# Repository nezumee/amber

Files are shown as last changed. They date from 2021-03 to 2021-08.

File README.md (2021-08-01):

# Amber
Personalized split keyboard based on [Zebra](https://github.com/nezumee/zebra) experimentation.

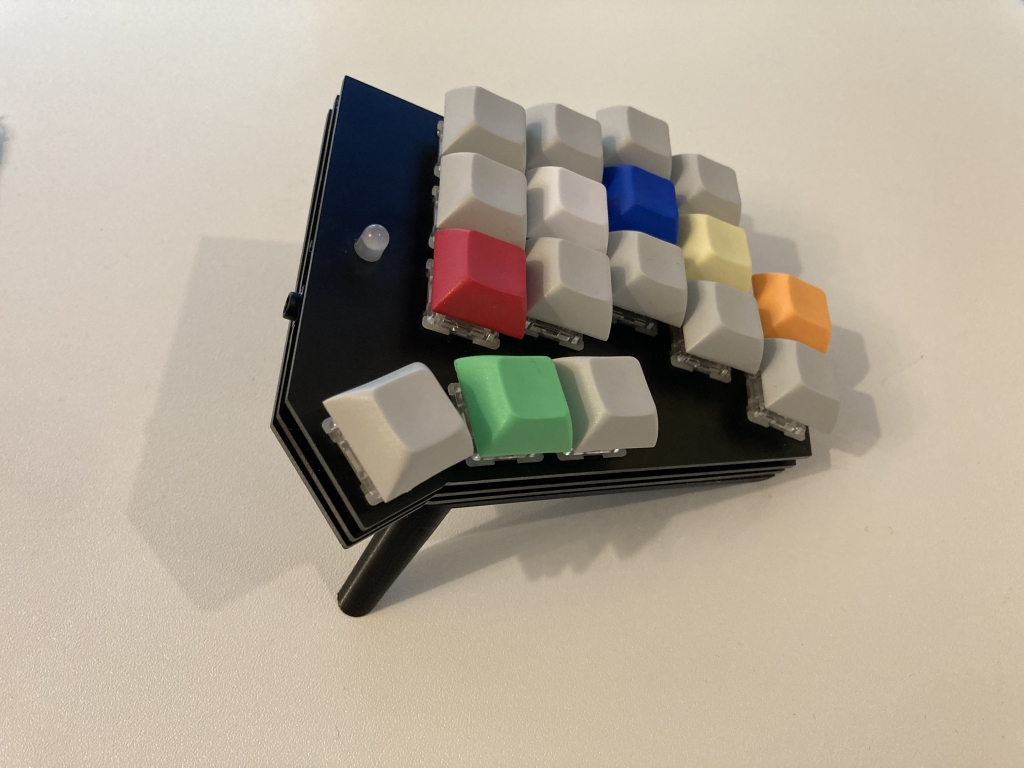
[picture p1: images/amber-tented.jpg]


# Bill of material

* PCB x2, switch plate PCB x2, bottom plate PCB x2 (see [gerber](gerber), all PCBs are reversible)
* ProMicro or equivalent x2 (if using something other than ProMicro, check if it will fit in the PCB cutout!)
* Peel-A-Way sockets x48 pins (https://keeb.io/products/peel-a-way-sockets-for-pro-micros)
* Mid-mount TRRS jack x2 (https://www.digikey.com/en/products/detail/cui-devices/SJ-43504-SMT-TR/2625173 or PJ342C in https://www.aliexpress.com/item/1005001299482943.html)
* Tactile switch x2 (https://www.digikey.com/en/products/detail/panasonic-electronic-components/EVQ-P7C01P/4429458)
* RGB LED x2 (https://www.digikey.com/en/products/detail/inolux/HV-5RGB60/7604616 or compatible)
* 1k Ohm resistor in 1206 size x2 (or other value, depending on how bright you want the indicator LED to be)
* EC11 rotary encoders x0-2
* N4148 x32 in DO-35 (through hole) or SOD123 (surface mount) form factor
* KailH sockets x32-34 (you need less than 34 if using encoders)
* Cherry MX compatible switches x32-34
* Keycaps
* TRRS cable

# Making a PCB sandwich keyboard starting with an ergogen definition
This design was created with help of the https://github.com/mrzealot/ergogen tool that makes it easier to generate keyboard plates and PCBs.

Rough steps used:
1. Generate PCB and outlines using ergogen: [ergogen.yaml](ergogen.yaml)
2. Create a Kicad schematic with switches and diodes, matching the ids created by ergogen, make a PCB based on that
3. Overwrite the Kicad PCB with the one coming from ergogen
4. Update PCB from schematic, preserving references but updating the nets and footprints as needed
5. Import the edges layer from ergogen outline, keep default position so outline matches the switch positions
6. Continue designing the PCB in Kicad as normal

# Fitting the ProMicro between the switch plate and PCB
Many keyboards using ProMicro (like Corne) either have the ProMicro exposed, or use a small plate to cover it separately from the switch plate. While the tech prototype look of showing the MCU is nice, sometimes you want something cleaner looking, and also less prone to gathering visible dust. With this in mind, I decided to make the front plate that serves both as a plate for the switches and also covers all the components on the PCB. This led to a few challenges:

1. Fit the ProMicro and its socket (yes, I didn't want to solder it to the PCB directly) between the PCB and the front plate. This required a surprising amount of effort:
  * Use the thinnest sockets I could find - Peel-a-way sockets (https://keeb.io/products/peel-a-way-sockets-for-pro-micros). They seem to be difficult to source, luckily I got some beforehand. Note that these sockets require bigger holes than you would normally have. My first iteration of the PCB had too narrow holes so they could not fit. 1.1mm in the second version is enough:
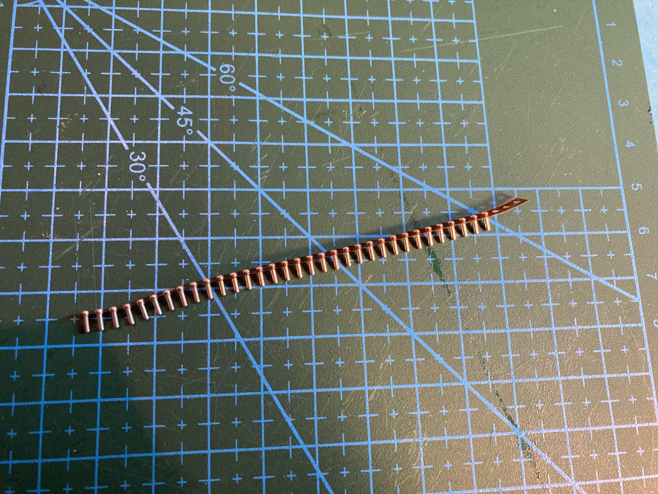
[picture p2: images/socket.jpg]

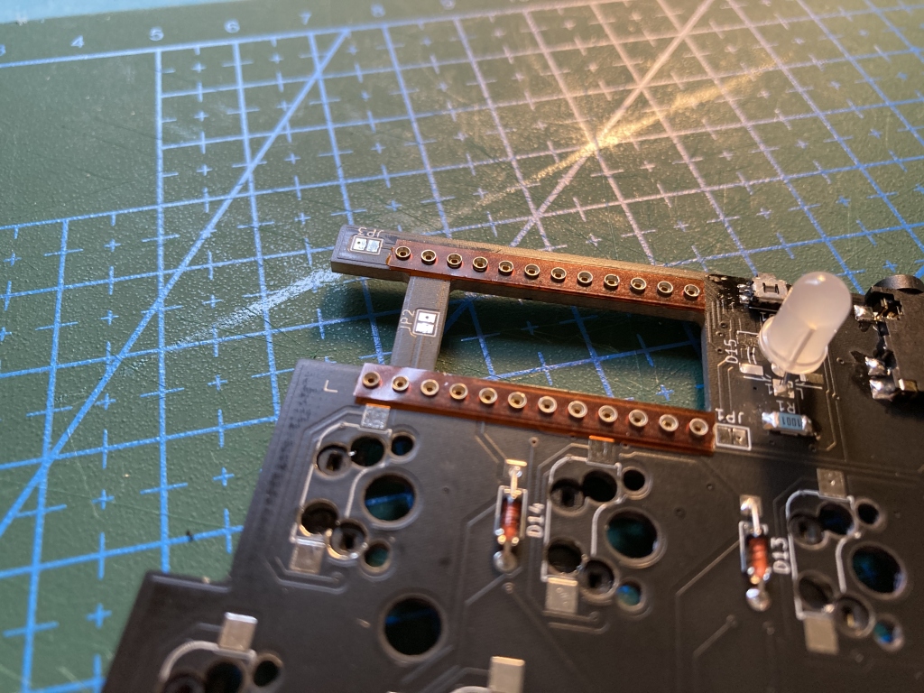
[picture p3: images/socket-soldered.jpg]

  * Mount ProMicro upside down
  * Make a cutout in the PCB to fit the components on ProMicro
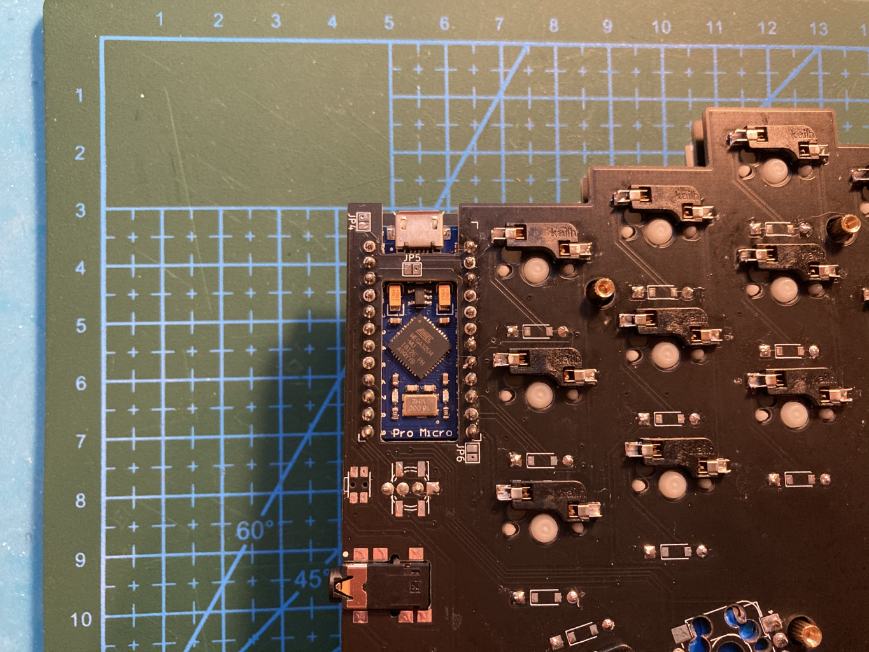
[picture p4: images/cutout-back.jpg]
 
  * The cutout and the fact that ProMicro is stuck between switches and the end of the board made routing quite difficult. Leaving a bridge between the left and right pin columns helped, but common ways of making reversible PCBs couldn't work. There is no space for dual ProMicro footprint, and I cannot reverse the ProMicro either since it becomes too tall to fit. I didn't want to mount it below the PCB either since there's even less space there.
  * To make the PCB reversible, I ended up using different pinouts for the left and right halves. For example, the index finger column (CI) is connected to B2 on the left side, but is mirrored to B4 on the right. This solved most of the pins at the cost of complicating firmware. A few that could not be reassigned, like VCC. For those, I added jumpers that are cut and soldered depending on which side is being built. For left side, you connect J1-J3 and cut J4-J6 (default). For the right side, you do the opposite.
 
2. Fit a TRRS jack between the plates. The jack commonly used is even thicker than ProMicro with a socket. Luckily, it turned out there are special mid-mount jacks that mount into a cutout in the PCB: CUI Devices SJ-4350 series available on DigiKey, or PJ342C available on AliExpress (I got both; despite the differences in diagrams on seller sites, the ones I got look identical).

3. Fit a reset button between the plates. This was straightforward, there's a number of thin tactile buttons available. I picked a small switch with button on the side. It turned out to be difficult to press, but I feel it's not a big deal since I don't use it often. Reset command can be added somewhere in the layout if needed.

With this, everything fits between the plates comfortably:
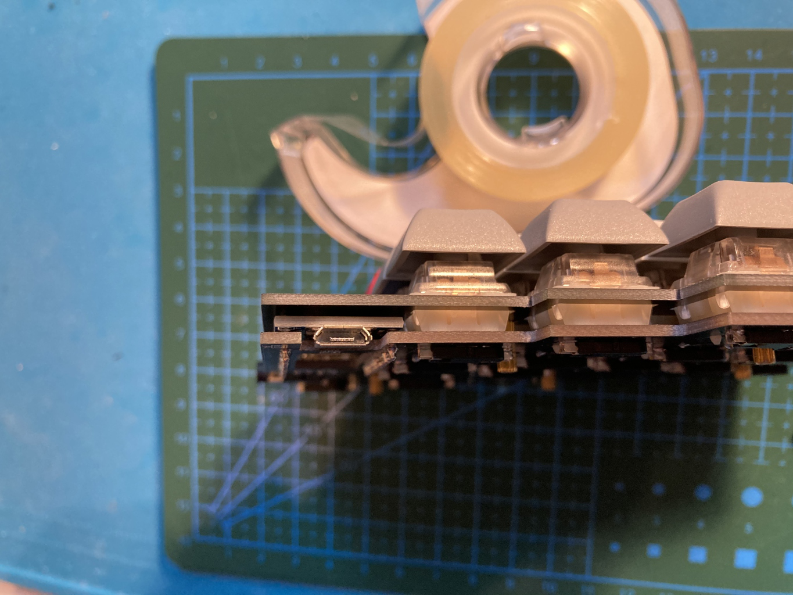
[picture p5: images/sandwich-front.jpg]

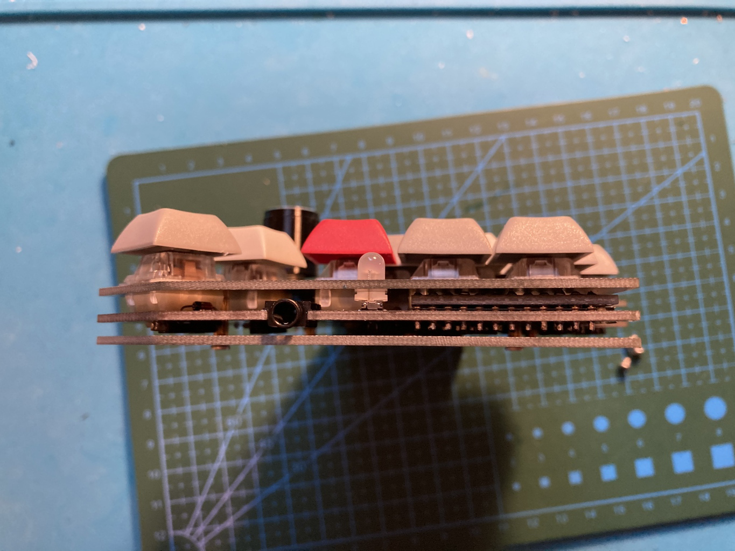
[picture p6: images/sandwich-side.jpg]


Of course, I waste all this effort by almost always using the keyboard with tented legs, attached using magnets: [Things/Tented-base.stl](Things/Tented-base.stl).

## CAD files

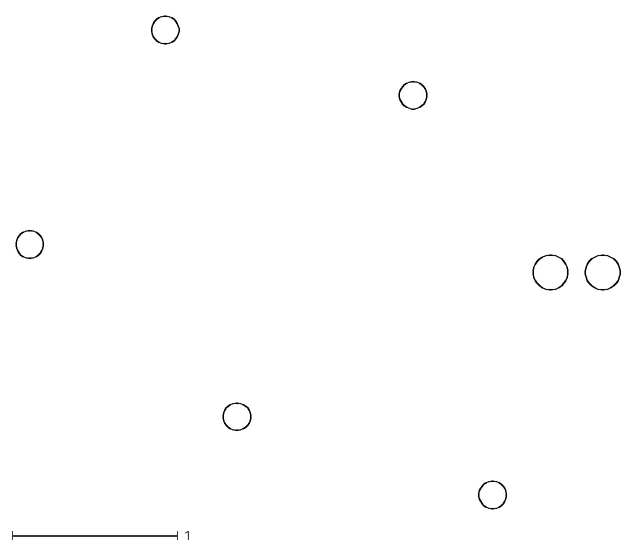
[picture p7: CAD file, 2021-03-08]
dxf/amber-plate-F_Cu.dxf
3.65 x 2.97

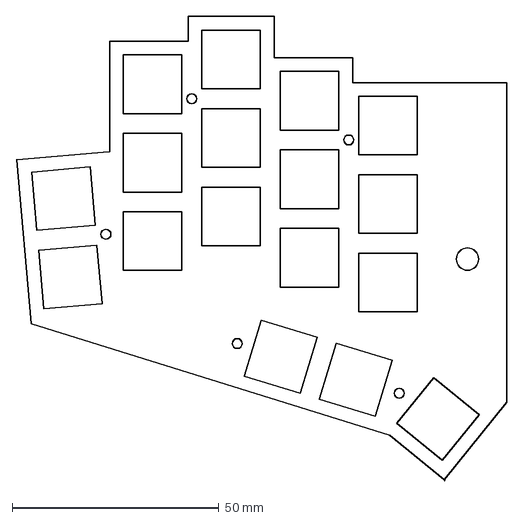
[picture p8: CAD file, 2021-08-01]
Metal case/Top plate small v7.dxf
118.8 x 112.3 mm

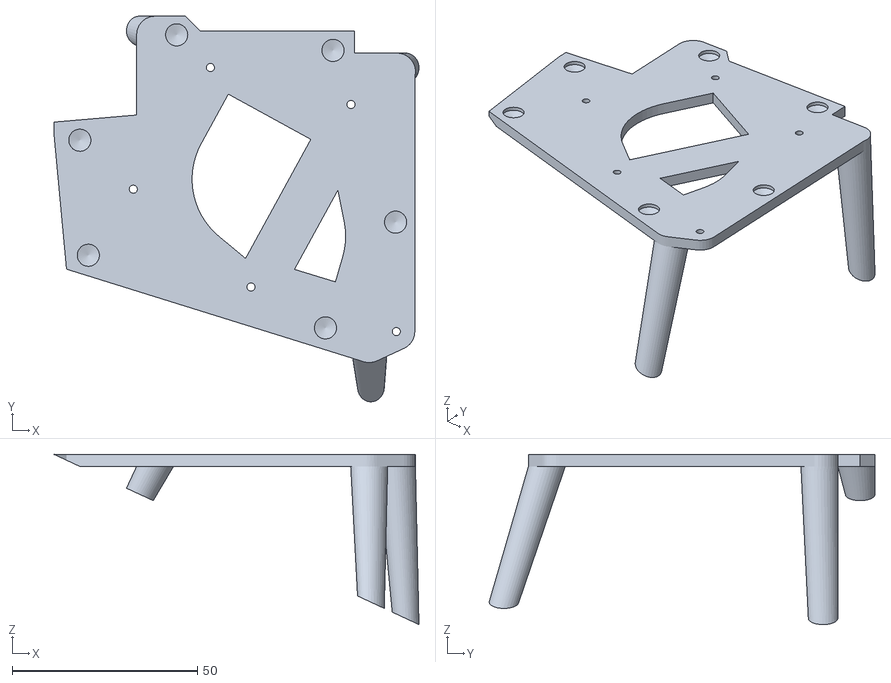
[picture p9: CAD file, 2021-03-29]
Things/Tented-base.stl
98.6 x 104.2 x 46.0

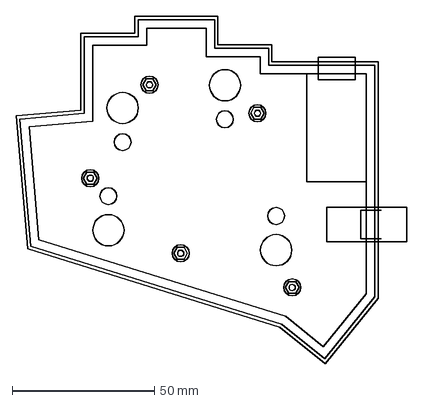
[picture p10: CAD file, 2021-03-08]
dxf/plate magnets.dxf
137.5 x 122.2 mm

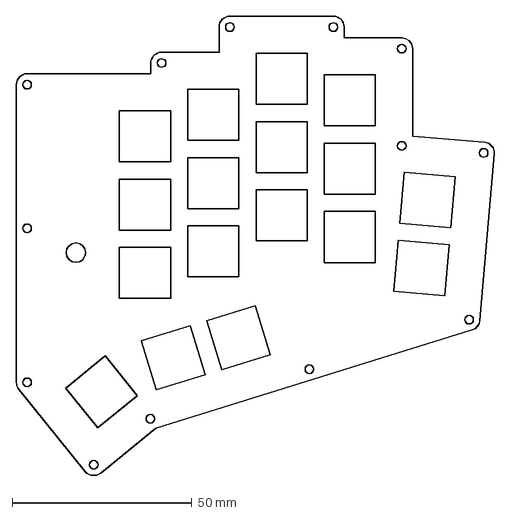
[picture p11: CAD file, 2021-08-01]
Metal case/Top plate mirror v8.dxf
133.0 x 127.8 mm

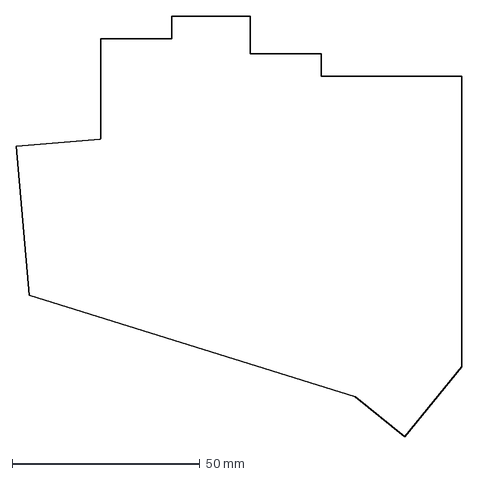
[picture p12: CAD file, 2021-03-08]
dxf/plate border simple.dxf
118.6 x 112.1 mm

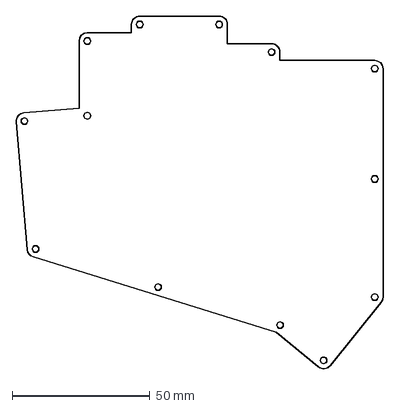
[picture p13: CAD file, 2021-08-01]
Metal case/Bottom plate v8.dxf
133.0 x 127.8 mm

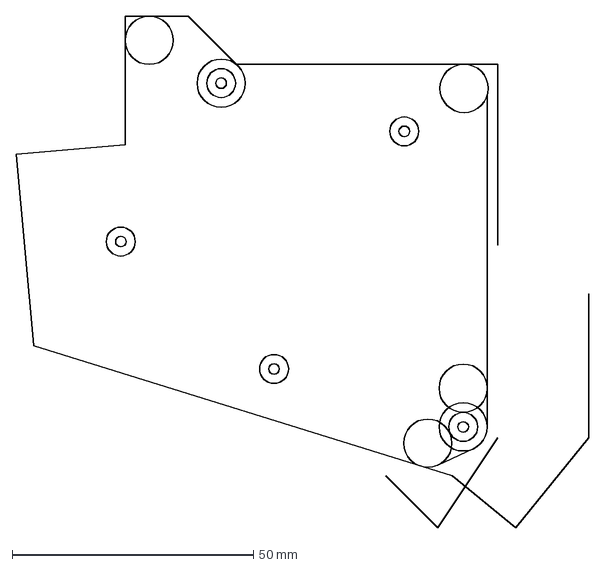
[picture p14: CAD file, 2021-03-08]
dxf/Mounting holes.dxf
118.8 x 106.1 mm

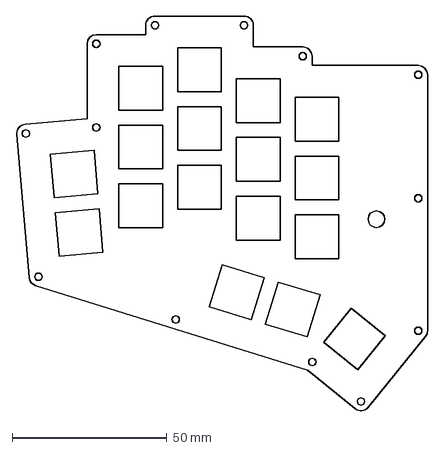
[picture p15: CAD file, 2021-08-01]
Metal case/Top plate v8.dxf
133.0 x 127.8 mm

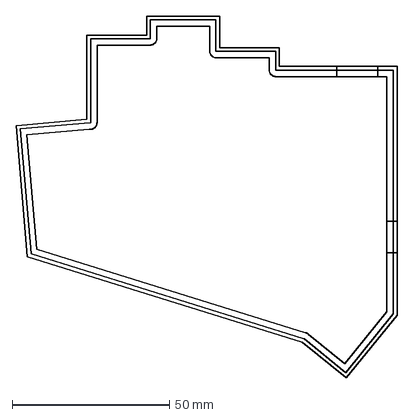
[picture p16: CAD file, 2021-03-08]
dxf/plate border.dxf
121.1 x 115.0 mm

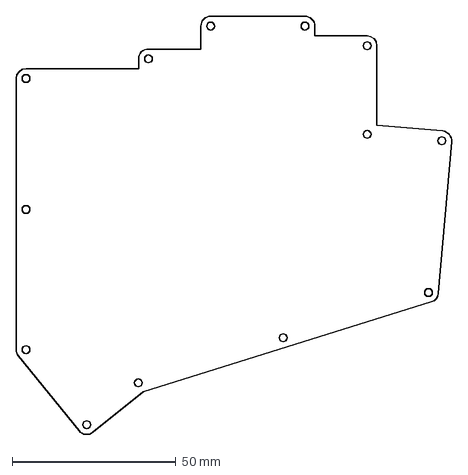
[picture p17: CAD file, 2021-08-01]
Metal case/Bottom plate mirror v8.dxf
133.0 x 127.8 mm

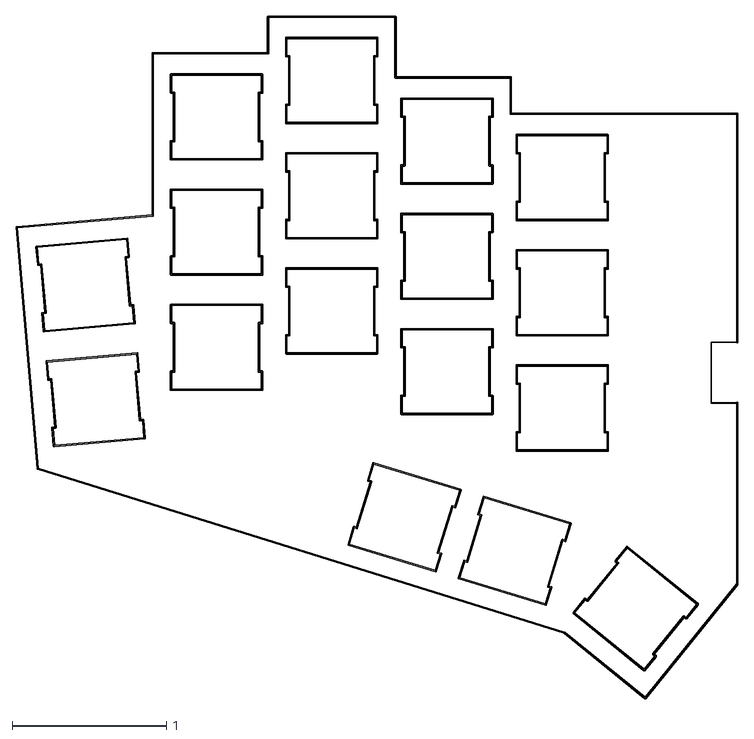
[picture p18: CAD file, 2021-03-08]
dxf/amber-plate-Edge_Cuts.dxf
4.69 x 4.43

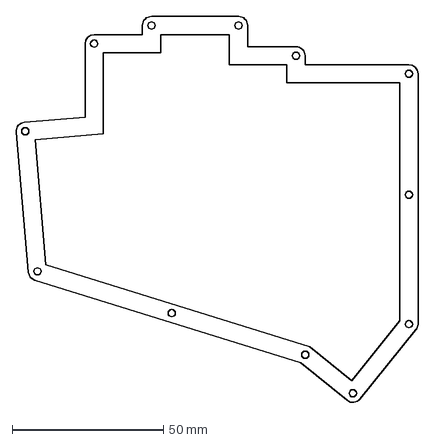
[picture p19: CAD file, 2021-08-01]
Metal case/Top border v8.dxf
133.0 x 127.8 mm

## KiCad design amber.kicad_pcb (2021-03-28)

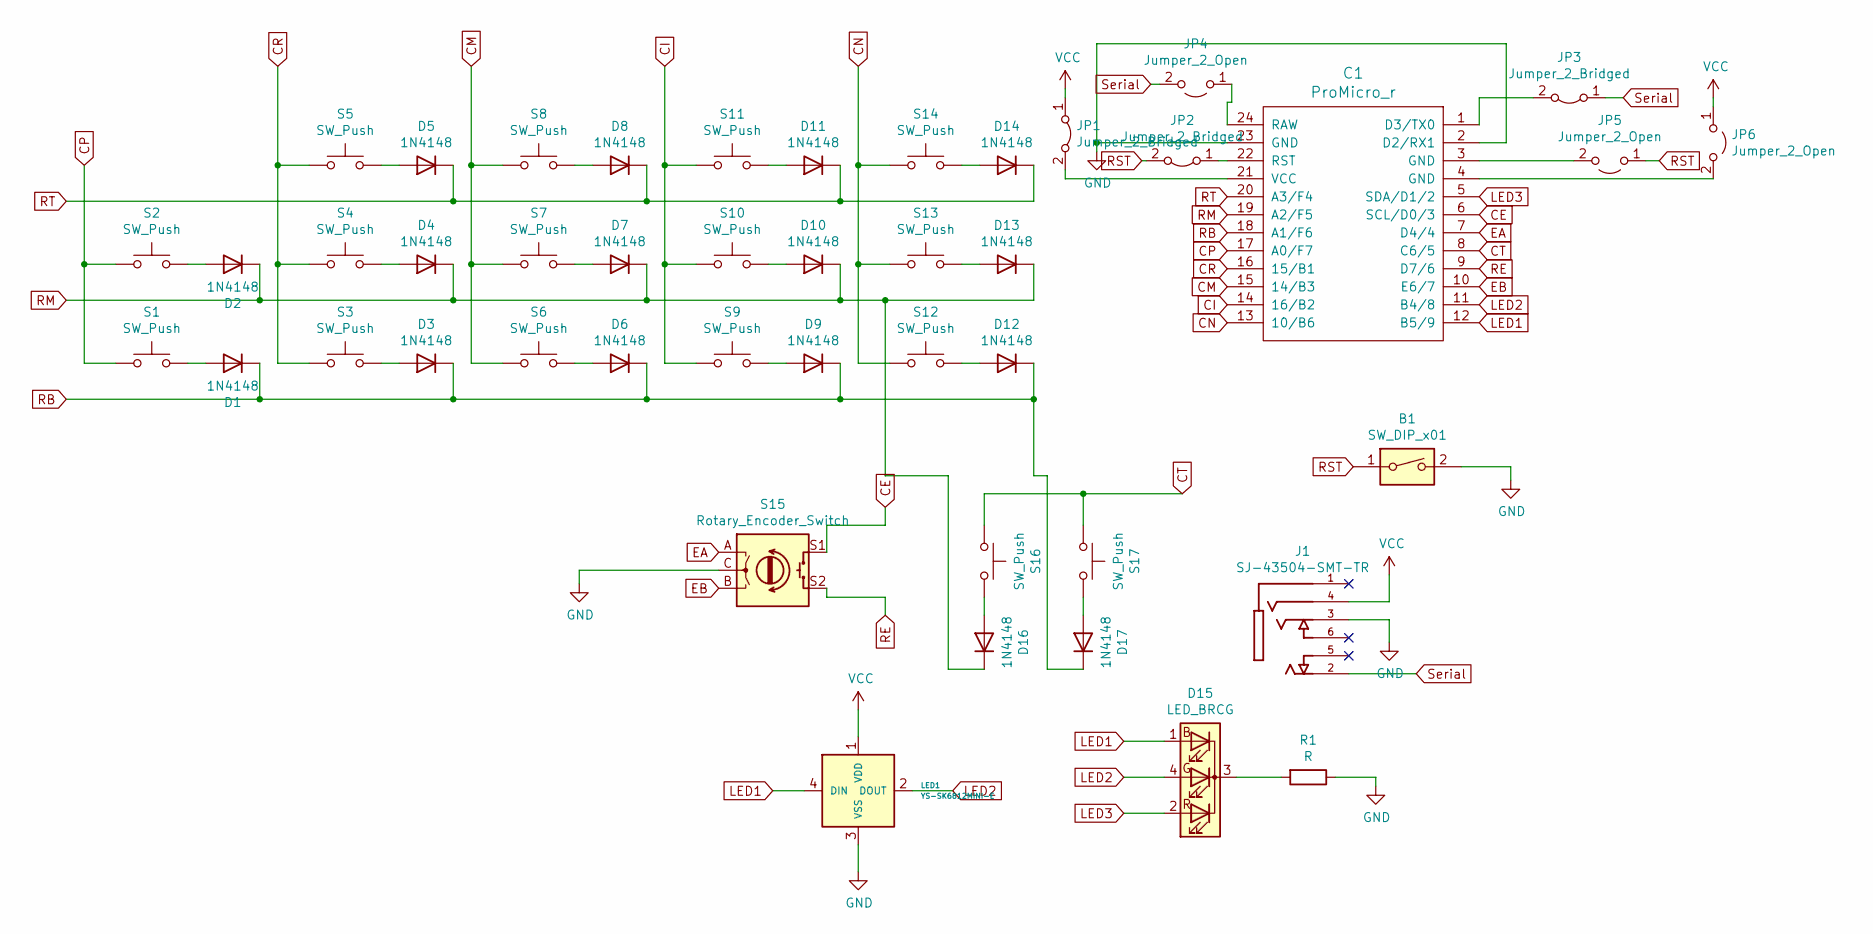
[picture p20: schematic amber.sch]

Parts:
B1: SW_DIP_x01; SW_SPST_EVQP7C
C1: ProMicro_r; ProMicro
D1, D2, D3, D4, D5, D6, D7, D8, D9, D10, D11, D12, D13, D14, D16, D17: 1N4148; Diode_THT7.6_SOD123
D15: LED_BRCG; LED_D5.0mm-4_RGB_Wide_Pins-dual
J1: SJ-43504-SMT-TR; CUI_SJ-43504-SMT-TR-dual
JP1, JP2, JP3: Jumper_2_Bridged; SolderJumper-2_P1.3mm_Bridged_Pad1.0x1.5mm
JP4, JP5, JP6: Jumper_2_Open; SolderJumper-2_P1.3mm_Open_Pad1.0x1.5mm
LED1: YS-SK6812MINI-E; LED_WS2812B-PLCC4-dual
R1: R; R_1206_3216Metric_Pad1.30x1.75mm_HandSolder
S1, S2, S3, S4, S5, S6, S7, S8, S9, S10, S11, S12, S13, S14, S16, S17: SW_Push; CherryMX_MidHeight_Hotswap
S15: Rotary_Encoder_Switch; Switch_MX2side_Encoder

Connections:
CE: C1.6 (SCL/D0/3), S15.S1
CI: C1.14 (16/B2), S9.1, S10.1, S11.1
CM: C1.15 (14/B3), S6.1, S7.1, S8.1
CN: C1.13 (10/B6), S12.1, S13.1, S14.1
CP: C1.17 (A0/F7), S1.1, S2.1
CR: C1.16 (15/B1), S3.1, S4.1, S5.1
CT: C1.8 (C6/5), S16.1, S17.1
EA: C1.7 (D4/4), S15.A
EB: C1.10 (E6/7), S15.B
GND: B1.2, C1.2 (D2/RX1), C1.23 (GND), J1.3, LED1.3 (VSS), R1.1, S15.C
LED1: C1.12 (B5/9), D15.1 (BA), LED1.4 (DIN)
LED2: C1.11 (B4/8), D15.4 (GA), LED1.2 (DOUT)
LED3: C1.5 (SDA/D1/2), D15.2 (RA)
unnamed: C1.1 (D3/TX0), JP3.2 (B)
unnamed: C1.3 (GND), JP5.2 (B)
unnamed: C1.4 (GND), JP6.2 (B)
unnamed: C1.21 (VCC), JP1.2 (B)
unnamed: C1.22 (RST), JP2.1 (A)
unnamed: C1.24 (RAW), JP4.1 (A)
unnamed: D1.2 (A), S1.2
unnamed: D2.2 (A), S2.2
unnamed: D3.2 (A), S3.2
unnamed: D4.2 (A), S4.2
unnamed: D5.2 (A), S5.2
unnamed: D6.2 (A), S6.2
unnamed: D7.2 (A), S7.2
unnamed: D8.2 (A), S8.2
unnamed: D9.2 (A), S9.2
unnamed: D10.2 (A), S10.2
unnamed: D11.2 (A), S11.2
unnamed: D12.2 (A), S12.2
unnamed: D13.2 (A), S13.2
unnamed: D14.2 (A), S14.2
unnamed: D15.3 (K), R1.2
unnamed: D16.2 (A), S16.2
unnamed: D17.2 (A), S17.2
RB: C1.18 (A1/F6), D1.1 (K), D3.1 (K), D6.1 (K), D9.1 (K), D12.1 (K), D17.1 (K)
RE: C1.9 (D7/6), S15.S2
RM: C1.19 (A2/F5), D2.1 (K), D4.1 (K), D7.1 (K), D10.1 (K), D13.1 (K), D16.1 (K)
RST: B1.1, JP2.2 (B), JP5.1 (A)
RT: C1.20 (A3/F4), D5.1 (K), D8.1 (K), D11.1 (K), D14.1 (K)
Serial: J1.2, JP3.1 (A), JP4.2 (B)
VCC: J1.4, JP1.1 (A), JP6.1 (A), LED1.1 (VDD)

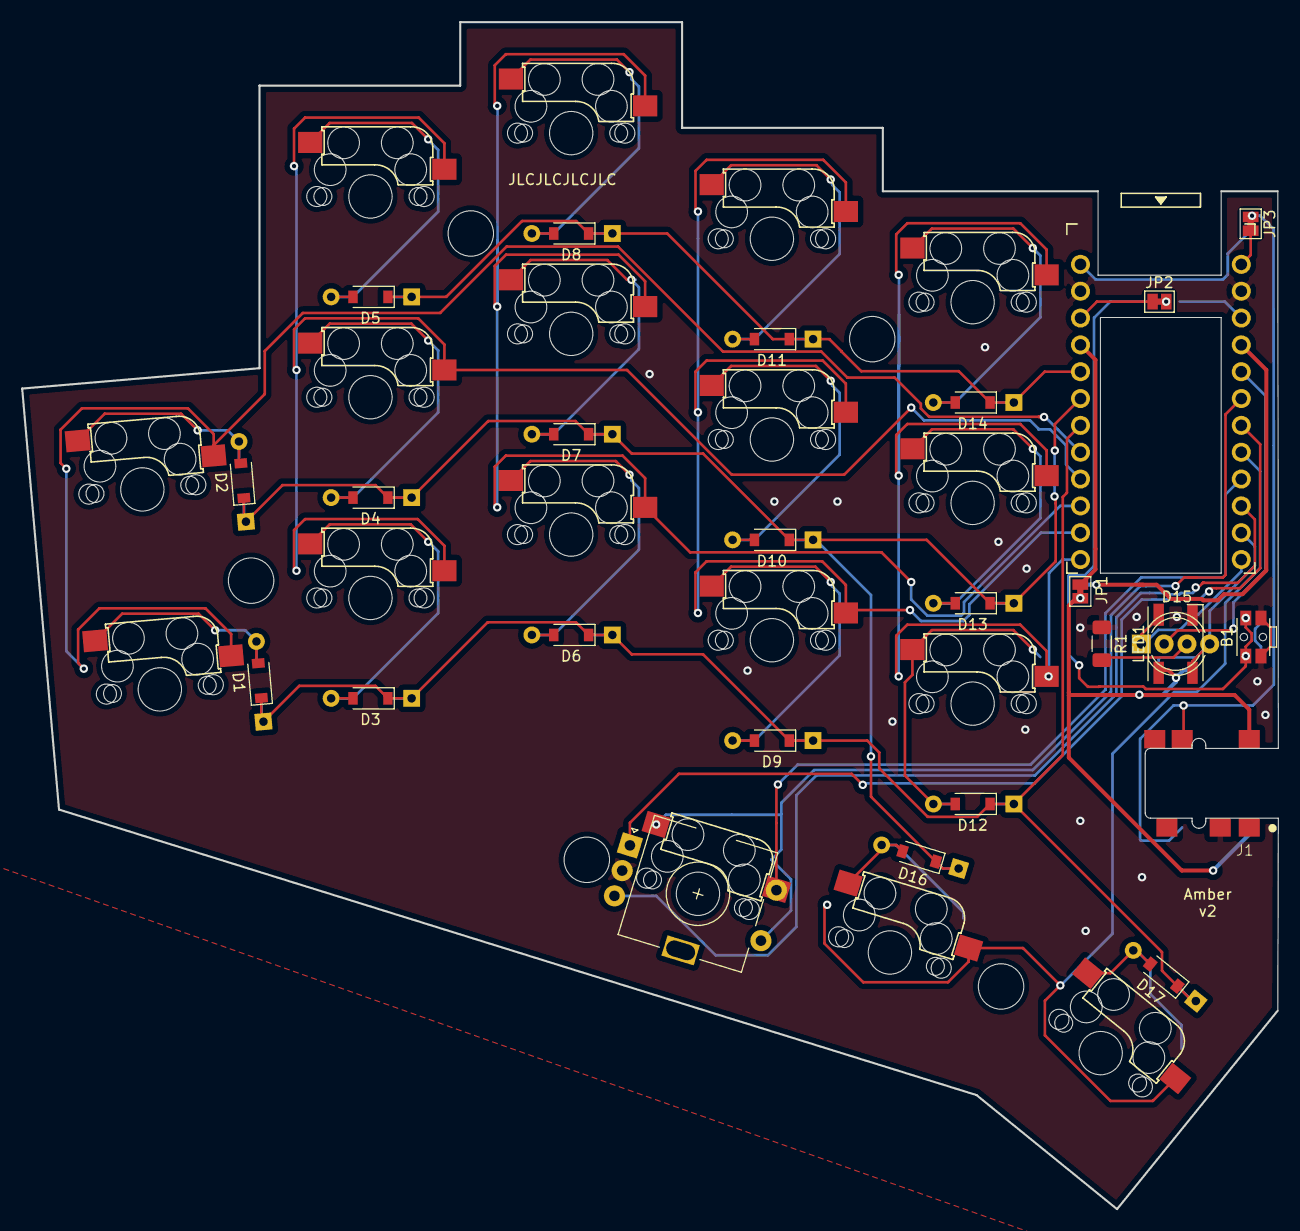
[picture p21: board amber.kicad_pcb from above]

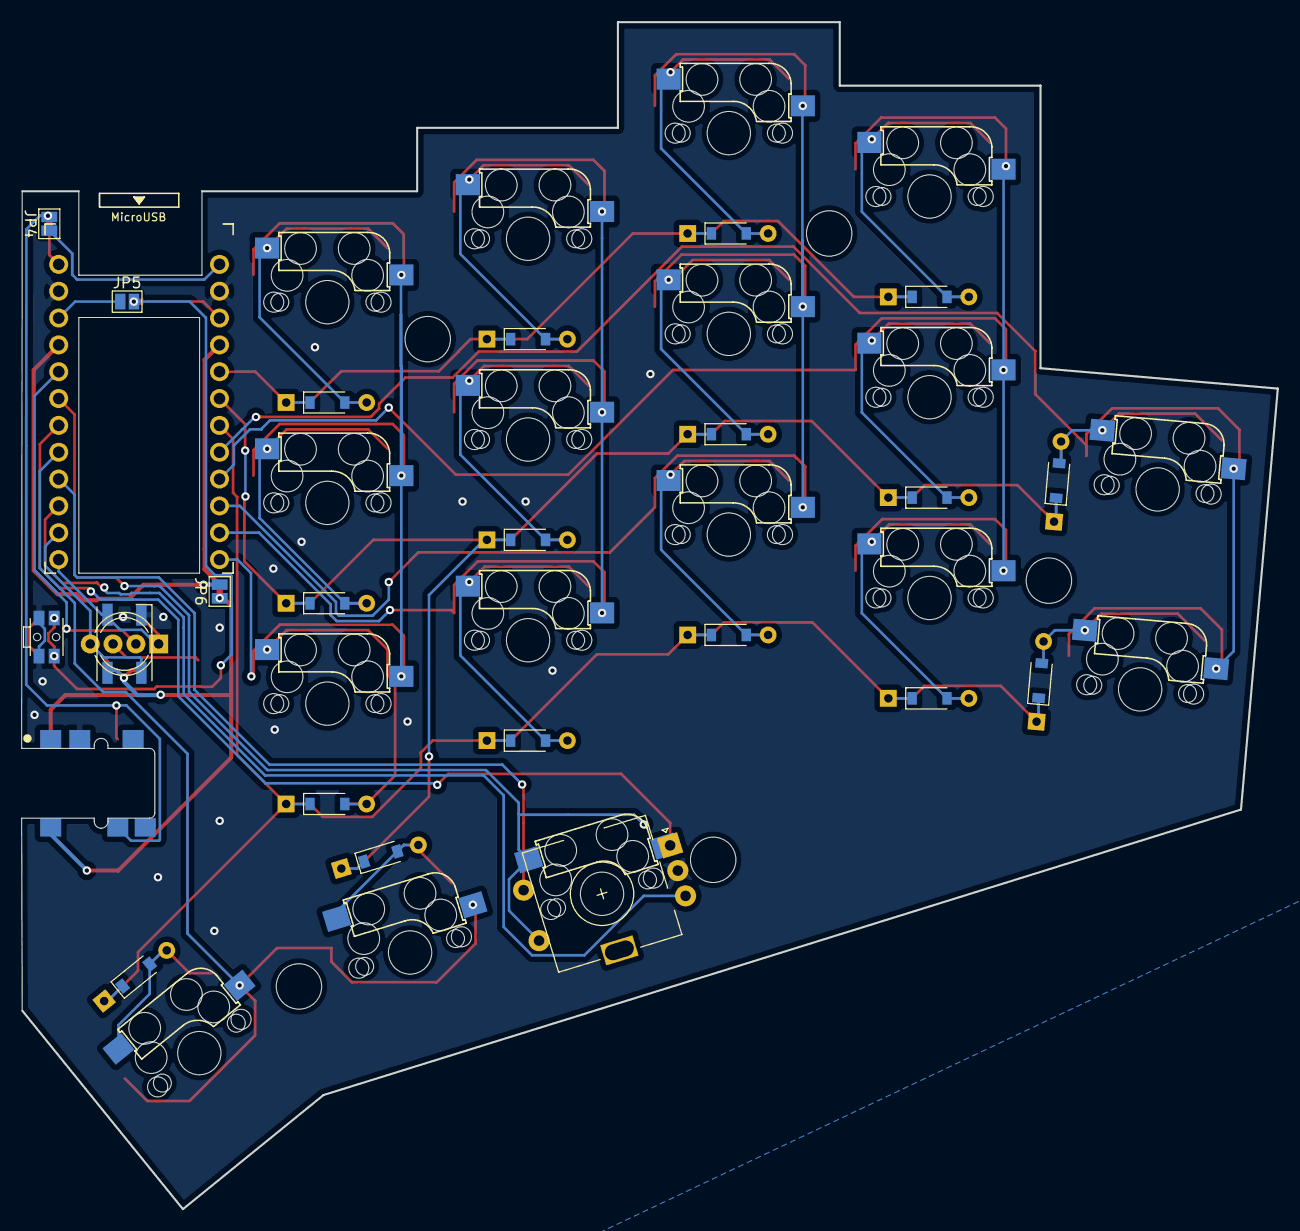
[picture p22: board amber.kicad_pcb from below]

Board: 2 copper layers, 118.9 x 112.3 mm, 50 parts (3 on the bottom side), 43 nets.

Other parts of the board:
P1, P2, P3, P4, P5: M2_HOLE_v2

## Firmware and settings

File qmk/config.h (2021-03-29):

#ifndef CONFIG_H
#define CONFIG_H

#include "config_common.h"

/* USB Device descriptor parameter */
#define VENDOR_ID       0xFEED
#define PRODUCT_ID      0x6063
#define DEVICE_VER      0x0002
#define MANUFACTURER    nezumee
#define PRODUCT         amber
#define DESCRIPTION     Amber

/* key matrix size */
#define MATRIX_ROWS 8
#define MATRIX_COLS 7

/* key matrix pins */
#define MATRIX_ROW_PINS { F4, F5, F6, D7 }
#define MATRIX_COL_PINS { F7, B1, B3, B2, B6, C6, D0 }
#define MATRIX_ROW_PINS_RIGHT { D1, D0, D4, B1 }
#define MATRIX_COL_PINS_RIGHT { C6, D7, E6, B4, B5, F7, F5 }
#define UNUSED_PINS

/* COL2ROW or ROW2COL */
#define DIODE_DIRECTION COL2ROW

/* Set 0 if debouncing isn't needed */
#define DEBOUNCING_DELAY 20
#define DEBOUNCE 20

#define ENCODERS_PAD_A { E6 }
#define ENCODERS_PAD_B { D4 }

#define ENCODERS_PAD_A_RIGHT { B3 }
#define ENCODERS_PAD_B_RIGHT { F6 }

/* Mechanical locking support. Use KC_LCAP, KC_LNUM or KC_LSCR instead in keymap */
#define LOCKING_SUPPORT_ENABLE

/* Locking resynchronize hack */
#define LOCKING_RESYNC_ENABLE
#define SOFT_SERIAL_PIN D3

/* key combination for command */
#define IS_COMMAND() ( \
    keyboard_report->mods == (MOD_BIT(KC_LSHIFT) | MOD_BIT(KC_RSHIFT)) \
)

/* prevent stuck modifiers */
#define PREVENT_STUCK_MODIFIERS


#ifdef RGB_DI_PIN
#define RGBLIGHT_ANIMATIONS
#define RGBLED_NUM 0
#define RGBLIGHT_HUE_STEP 8
#define RGBLIGHT_SAT_STEP 8
#define RGBLIGHT_VAL_STEP 8
#endif

#endif

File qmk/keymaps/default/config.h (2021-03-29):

// generated from users/manna-harbour_miryoku/miryoku.org  -*- buffer-read-only: t -*-

#pragma once

// default but important
#define TAPPING_TERM 170
#define TAPPING_TERM_PER_KEY

// Prevent normal rollover on alphas from accidentally triggering mods.
#define IGNORE_MOD_TAP_INTERRUPT

// Enable rapid switch from tap to hold, disables double tap hold auto-repeat.
// #define TAPPING_FORCE_HOLD

// Recommended for heavy chording.
// #define QMK_KEYS_PER_SCAN 4

// Mouse key speed and acceleration.
#undef MOUSEKEY_DELAY
#define MOUSEKEY_DELAY          0
#undef MOUSEKEY_INTERVAL
#define MOUSEKEY_INTERVAL       16
#undef MOUSEKEY_WHEEL_DELAY
#define MOUSEKEY_WHEEL_DELAY    0
#undef MOUSEKEY_MAX_SPEED
#define MOUSEKEY_MAX_SPEED      6
#undef MOUSEKEY_TIME_TO_MAX
#define MOUSEKEY_TIME_TO_MAX    64

#define COMBO_COUNT 21

#define TAPPING_FORCE_HOLD_PER_KEY

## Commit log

2021-02-08 Add Amber v1
    [amber-plate.kicad_pcb, amber.kicad_pcb, amber.sch]
2021-03-08 Add case drawings
    [Mounting holes.dxf, amber-plate-Edge_Cuts.dxf, amber-plate-F_Cu.dxf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]
2021-03-08 Use a mid-mount TRRS jack SJ 43504
    [amber.kicad_pcb, amber.sch]
2021-03-08 Widen the promicro pad holes
    [amber.kicad_pcb, amber.sch]
2021-03-08 Move serial to D1
    [amber.kicad_pcb, amber.sch]
2021-03-08 Add magnets, use side switch for reset
    [amber.kicad_pcb, amber.sch]
2021-03-08 Prettify the ground vias
    [amber.kicad_pcb]
2021-03-09 Update silkscreen
    [amber.kicad_pcb, amber.sch]
2021-03-09 Make a reversible MCU socket using jumpers
    [amber.kicad_pcb, amber.sch]
2021-03-14 Fix the encoder/switch footprint
    [amber.kicad_pcb, amber.sch]
2021-03-14 Let standoffs go through the PCB
    [amber.kicad_pcb]
2021-03-14 Remove the reset button cutout in the plate
    [amber-plate.kicad_pcb]
2021-03-14 Add bottom plate
    [amber-bottomplate.kicad_pcb]
2021-03-14 Update metadata
    [amber-bottomplate.kicad_pcb, amber-plate.kicad_pcb, amber.kicad_pcb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]
2021-03-15 Replace 2 LEDs with one 5mm
    [amber-plate.kicad_pcb, amber.kicad_pcb, amber.sch]
2021-03-15 Add a pixel LED indicator option
    [amber.kicad_pcb, amber.sch]
2021-03-15 Make pixel LEDs easier to solder
    [amber.kicad_pcb, amber.sch]
2021-03-15 Cleanup tracks
    [amber.kicad_pcb]
2021-03-15 Add a plate with rough extension for gasket mount
    [amber-plate-extended.kicad_pcb]
2021-03-15 Create gerbers for v2
    Also shorten a gasket mount flap a bit in extended plate
    [amber-plate-extended.kicad_pcb]
2021-03-28 Move magnets to where they can be added in the tented print
    [amber.kicad_pcb]
2021-03-29 Add tented base
    [Tented-base.stl]
2021-08-01 Add metal case files
    [Bottom plate mirror v8.dxf, Bottom plate v8.dxf, Top border v8.dxf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]
